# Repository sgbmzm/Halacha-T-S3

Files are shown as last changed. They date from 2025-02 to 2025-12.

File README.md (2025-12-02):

# Halacha-watch-T-DISPLAY-S3

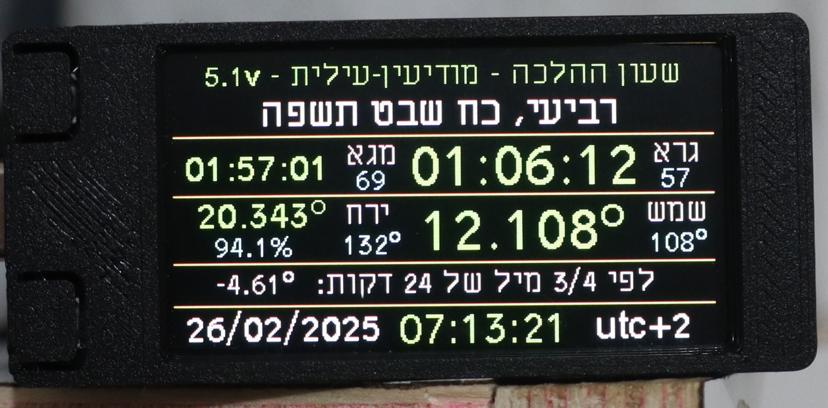
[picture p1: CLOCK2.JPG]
clock


## License  
**The file `main_shemesh_s3` is for personal use only!**  
**Modification is strictly prohibited.** You may use it as-is, but you may not edit, modify, or alter its content.  
**Commercial use is forbidden.** If you wish to use `main_shemesh_s3` for business or organizational purposes, please contact the author.  

Other files in this repository may have different licensing terms.

I would especially like to mention and thank the following important things that are freely licensed and I use them:
1. https://github.com/russhughes/s3lcd/blob/main/firmware/GENERIC_S3_OCT_16M/firmware.bin
2. https://github.com/peterhinch/micropython-samples/tree/d2929df1b4556e71fcfd7d83afd9cf3ffd98fdac/astronomy

## hardware

The hardware needed is:
This microcontroller:
https://lilygo.cc/products/t-display-s3?variant=42284559827125
solder 5 pins to it for an RTC clock called: **DS3231 MINI**
G+NC+16+21+17 (next to each other)
(DS3231 MINI can be purchased separately on AliExpress and includes a backup battery for the clock)

Attention! To prevent the DS3231 backup battery from draining quickly, it is very important to remove the 2 PULL_UP resistors located on the back of the main board and responsible for pins 16 and 17 according to the instructions here. They must be carefully removed with a soldering iron.

https://github.com/Xinyuan-LilyGO/T-Display-S3/issues/313





BATTERY:



**Please note: You need to request that the order of the wires be as shown here in the picture down**

A6b3ef4dbb0394ad195ca8c3004ead0fc0

5 pcs 3.7V 650mAh Lipo Polymer Lithium Rechargeable Battery + JST 1.25mm 2pin Plug 602248 For MP3 GPS Recorder Headset Camera

https://aliexpress.com/item/1005001397326160.html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

## INSTALL

First install (using Tony) the file:
https://github.com/sgbmzm/Halacha-T-S3/blob/main/rom/firmware_t_display_s3_s3lcd.bin
or directly from here:
https://github.com/russhughes/s3lcd/blob/main/firmware/GENERIC_S3_OCT_16M/firmware.bin

Then connect to WIFI and install the necessary files using the following code:

```
import network
import time

# פרטי הרשת שלך
SSID = "SSID_NAME" # Enter your network name (as string).
PASSWORD = "123456789" # Enter your network password (as string).

def connect_wifi():
    wlan = network.WLAN(network.STA_IF)  # מצב תחנת WiFi
    wlan.active(True)  # הפעלת WiFi
    if not wlan.isconnected():
        print("מתחבר לרשת WiFi...")
        wlan.connect(SSID, PASSWORD)  # חיבור לרשת
        while not wlan.isconnected():
            time.sleep(1)  # המתן לחיבור
    print("מחובר ל-WiFi בהצלחה!")
    print("כתובת IP:", wlan.ifconfig()[0])  # הצגת כתובת IP

# קריאה לפונקציה
connect_wifi()

import mip
mip.install("github:sgbmzm/Halacha-T-S3/package.json",target="/")
```

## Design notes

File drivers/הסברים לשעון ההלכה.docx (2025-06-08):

בס"ד

שעון ההלכה

מאת: שמחה גרשון בורר (מתכנת "כוכבים וזמנים") 052-766-1249 - sgbmzm@gmail.com

כל הזכויות שמורות

המטרה הכללית של שעון ההלכה היא: לתת את מקורות זמני ההלכה במקום את תרגומם לשעון הרגיל: 1. שעון כללי לזמני הלכה: שעות זמניות. 2. כל זמני צאת הכוכבים ועלות השחר: גובה/עומק השמש במעלות זווית תחת האופק, שזה הגורם הראשי הקובע את רמת החשיכה (ניתן להמרה ממקום למקום ומעונה לעונה).

בשעון ההלכה יש 6 שורות תצוגה:

1: כותרת, הכוללת בתוכה מיקום (עיר) ואחוזי הסוללה.

2. תאריך עברי (בשבת וחג ברקע צהוב, ובראש חודש וחול המועד ברקע טורקיז).

3. שעה זמנית לפי גר"א/מג"א וגם - מספר דקות בשעה זמנית/מספר שניות בדקה זמנית (כשבר עשרוני) - לפי השיטות הנ"ל.

4. גובה ואזימוט של השמש והירח ואחוזי הירח במסלולו החודשי ממולד למולד.

5: הסברים מתחלפים (תאריך הגרסה של שעון ההלכה מופיע מיד בתחילת ההסברים).

6: שעה בשעון רגיל, תאריך לועזי, והפרש הזמן המקומי מגריניץ (UTC).

וראו עוד הסברים להלן:

הסבר על שני הלחצנים

כששני הלחצנים בצד שמאל:

לחצן תחתון משמש להדלקה וכיבוי (לחיצה אחת קצרה).

לחצן עליון: משמש לביצוע פעולות כדלהלן

לחיצה קצרה: שינוי מיקום

לחיצה מתמשכת: הגדרת המיקום להיות מיקום ברירת מחדל כלומר שהוא המיקום שיהיה מיד כשיופעל המכשיר

הדלקה ומיד כשכתוב "מתחיל" לחיצה ארוכה על הלחצן העליון: עדכון השעון הפנימי

הדלקה בשני הלחצנים יחד: עדכון כל התוכנה

כל העדכונים דורשים שתהיה בסביבה רשת אלחוטית ללא סיסמה (כגון להפעיל נקודה חמה ללא סיסמה)

כללי

כשהשעון הפנימי מכוון: דיוק הזמנים 10 שניות, אבל: דיוק גובה הירח סוטה בכדקה

כששעון ההלכה אינו מחובר לחשמל הוא נכבה מעצמו אחרי כדקה וחצי, למעט בשבת וחג שאז נשאר דולק למשך כ- 8 שעות עד שנגמרת הבטרייה.

אחוז הסוללה (הערכה גסה בלבד) מופיע בשורת הכותרת מצד שמאל. כשמחובר לחשמל מופיע: %**

כשרואים דרך החור שיש בפנים אור אדום דולק: הסוללה נטענת. אם יש רק אור ירוק: הסוללה טעונה במלואה.

התאריך העברי מתחלף בשקיעה, ומהשקיעה ועד 23:59:59 מופיע "ליל" היום הבא.

מתחת הכיתוב גרא/מגא: דקות בשעה זמנית/שניות בדקה זמנית (כשבר עשרוני).

מתחת הכיתוב שמש/ירח: אזימוט שמש/ירח (אזימוט = מעלות זווית מהצפון, וכדלהלן: צפון=0/360, מזרח=90, דרום=180, מערב=270)

שלב הירח במסלולו החודשי - ממולד אמיתי למולד אמיתי – באחוזים - מתחת לגובה הירח: מולד אמיתי=0/100, ניגוד=50, רבָעִים=25/75

רשימת זמני היום בשעות זמניות

זריחה ושקיעה במישור: 00:00

סוף שמע ביום/רבע הלילה: 03:00

סוף תפילה ביום/שליש הלילה//סוף אכילת חמץ: 04:00

סוף שריפת חמץ: 05:00

חצות יום ולילה: 06:00

מנחה גדולה: 06:30 (ויש סוברים 30 דקות אחרי חצות)

להימנע מסעודה בערב שבת: 09:00

מנחה קטנה: 09:30

פלג המנחה: 10:45

הערה חשובה: שעה זמנית מג"א מחושב לפי 72 דקות בתקופת ניסן (בבוקר ובערב כדי שחצות יהיה בראש כל אדם) ומתורגם למעלות לפי שמש בגובה 16°- בבוקר ובערב. (שימו לב שברוב הלוחות נותנים זמן מג"א לפי 90 דקות שזה במעלות °19.75- אך דבר זה קשה להתאימו עם המציאות של הארת הרקיע בבוקר ובערב ולכן לא הבאתיו).

זמנים במעלות כשהשמש תחת האופק

זריחת ושקיעת מרכז השמש ללא התחשבות ברפרקציה (גאומטרי): 0.0°

זריחה ושקיעה נראים במישור וכשאין הסתרות: 0.833°-

זמני צאת הכוכבים 3/4 מיל מתורגמים למעלות

לפי מיל של 18 דקות: -3.65°

לפי מיל של 22.5 דקות: -4.2°

לפי מיל של 24 דקות: -4.61°

צאת כוכבים קטנים רצופים (בחגורת הצייד לפי תצפיות שלי): -6.3° (בין 6 ל 6.5 מעלות)

זמני עלות השחר/צאת כוכבים דר"ת מתורגמים למעלות

לפי 4 מיל של 18 דקות: -16.02°

לפי 4 מיל של 22.5 דקות: -19.75°

לפי 5 מיל של 24 דקות: -25.8°

משיכיר/תחילת ציצית ותפילין (משוער לפי תצפיות): -10.5°

להלן תנאי מינימום (בערך) הדרושים לראיית ירח ראשונה בחודש

שלב חודשי: 3%; וגם הפרש גובה שמש-ירח של 8°

פתרון תקלות:

בכל תקלה יש לנסות ללחוץ על לחצן האיפוס בחור שנמצא בחלק העליון.

בבליטה שמאחורי המכסה יש שעון פנימי שאמור לשמור על התאריך והשעה גם כשנגמרת הבטרייה, אך לפעמים הוא עושה בעיות. ניתן לנסות לכוון אותו באמצעות רשת אלחוטית ללא סיסמה וכדלעיל, ואם לא מועיל - אפשר להחליף אותו אצלי תמורת 5 ₪.

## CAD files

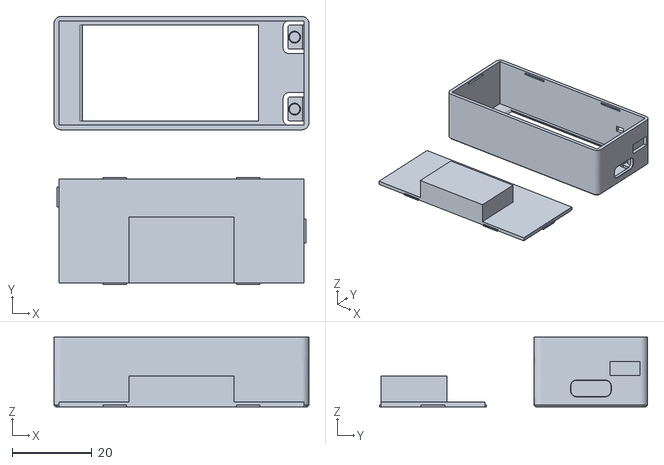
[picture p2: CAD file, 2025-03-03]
S3_SHELL_AND_COVER.stl
63.8 x 67.1 x 17.4

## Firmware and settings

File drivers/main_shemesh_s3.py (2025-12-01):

# ========================================================
# License: Personal Use Only  
# This file (`main_shemesh_s3.py`) is licensed for **personal use only**.  
# You may **not** modify, edit, or alter this file in any way.  
# Commercial use is strictly prohibited.  
# If you wish to use this file for business or organizational purposes,  
# please contact the author.  
# ========================================================

# משתנה גלובלי שמציין את גרסת התוכנה למעקב אחרי עדכונים
VERSION = "1/12/2025"

######################################################################################################################

# סיכום קצר על התוצאות המעשיות של הכפתורים בקוד הזה
# לחיצה על שתי הכפתורים בו זמנית כאשר מדליקים את המכשיר: עדכון תוכנת המכשיר
# אם כפתור המיקומים לחוץ בשעת הכניסה לתוכנה: עדכון השעון מהרשת 

# הבסיס של החישובים הגיע מכאן
# https://github.com/peterhinch/micropython-samples/tree/d2929df1b4556e71fcfd7d83afd9cf3ffd98fdac/astronomy
# לגבי בעיות עם המסך שבס"ד נפתרו ראו כאן
# https://github.com/Xinyuan-LilyGO/T-Display-S3/issues/300

import time, math, machine, utime, esp32, network, ntptime, os, ujson
from math import sin, cos, tan, radians, degrees
from machine import I2C, SoftI2C, Pin, ADC, PWM, RTC
import gc # חשוב נורא לניקוי הזיכרון
from halacha_clock.sun_moon_sgb import RiSet  # ספריית חישובי שמש
from halacha_clock.moonphase_sgb import MoonPhase  # ספריית חישובי שלב הירח
from halacha_clock.ds3231 import DS3231 # שעון חיצוני
from halacha_clock import mpy_heb_date # לחישוב תאריך עברי מתאריך לועזי. ספרייה שלי


# פונטים
import halacha_clock.miriam20 as FontHeb20
import halacha_clock.miriam25 as FontHeb25
import halacha_clock.miriam30 as FontHeb30
import halacha_clock.miriam40 as FontHeb40

# למסך
import halacha_clock.tft_config as tft_config
import s3lcd

# הגדרת המסך
tft = tft_config.config(rotation=3) # כיוון סיבוב התצוגה שאני רוצה בגלל הבליטה של השעון החיצוני
tft.init() # כך חייבים לעשות

####################################################################3


# הגדרת הכפתורים הפיזיים במכשיר
boot_button = Pin(0, Pin.IN, Pin.PULL_UP) # משמש בקוד לשינוי המיקומים ולקביעת מיקום ברירת מחדל
button_14 = Pin(14, Pin.IN, Pin.PULL_UP) # משמש בקוד להכנסת המכשיר למצב שינה ולהתעוררות ולשליטה על הכוח

    
# משתנה למעקב אחר מצב הכוח כלומר האם המכשיר כבוי או פועל
# המשמעות של זה מגיעה לידי ביטוי בפונקצייה הראשית: main
# זה משתנה חשוב נורא
power_state = True

# משתנה מאוד חשוב שמגדיר האם המכשיר ייכנס למצב שינה אוטומטי לאחר מספר דקות של פעילות
# המשתנה הזה מוגדר בתוך פונקציית main_halach_clock לפי אם שבת או יום חול
automatic_deepsleep = False

##########################################################################################################
# הגדרת ADC על GPIO4 לצורך קריאת כמה מתח המכשיר מקבל
adc = ADC(Pin(4))  
adc.atten(ADC.ATTN_11DB)  # קביעת טווח מתח עד כ-3.6V
adc.width(ADC.WIDTH_12BIT)  # רזולוציה של 12 ביט (ערכים בין 0 ל-4095)

# משתנה חשוב שמגדיר מה המתח המירבי שיכול להיות לסוללה הפנימית ומעל זה קובעים שסימן שמחובר לחשמל או למקור מתח חיצוני
max_battery_v = 4.55

# משתנה מאוד חשוב ששומר את המתח בשנייה הקודמת כדי להשוות אליו ולבדוק האם חובר חשמל או נותק
# זה מתעדכן כל שנייה מחדש בפונקציית מיין-מיין
last_voltage = None # שומר את המתח האחרון שנמדד
last_battery_percentage = None # שומר את אחוזי הסוללה האחרונים שנמדדו
last_is_charging = None # שולט על כל הדברים שדורשים לדעת האם כעת המכשיר מחובר לחשמל

# פונקציה למדידת מתח סוללה מתוך ממוצע של 10 קריאות מתח
# מספר הקריאות משפיע על מהירות פעילות התוכנה. כמה שיותר קריאות התוכנה מתעכבת יותר !!!!!!!!!!!!!
def read_battery_voltage(samples=8):
    total = 0
    for _ in range(samples):
        total += adc.read()
        time.sleep(0.005)  # חצי מילישנייה בין קריאות
    avg = total / samples
    voltage = (avg / 4095) * 3.6 * 2  # המרה למתח אמיתי
    return voltage

# כדי לדעת אם מחובר כעת לחשמל, כדאי לבדוק מספר קריאות רצופות
# מספר הקריאות משפיע על מהירות פעילות התוכנה. כמה שיותר קריאות התוכנה מתעכבת יותר !!!!!!!!!!!!!!
def is_charging_function(voltage, threshold=max_battery_v, stable_reads=1):
    count = 0
    for _ in range(stable_reads):
        if read_battery_voltage() > threshold:
            count += 1
        time.sleep(0.005)
    return count >= stable_reads

def get_battery_percentage(voltage, min_voltage=3.6, max_voltage=4.4):
    """ מחשב אחוז סוללה על פי המתח הנמדד ומונע ערכים מחוץ לטווח 0%-100% """
    percentage = ((voltage - min_voltage) / (max_voltage - min_voltage)) * 100
    return round(max(0, min(100, percentage)))


##############################################3

# לאחר מכן להפעיל PWM כדי לשלוט במידת התאורה האחורית של המסך
BACKLIGHT = PWM(Pin(38, Pin.OUT), freq=2000) # ה: פרק, חשוב מאוד לגבי התדר וקובע גם את סוג הצפצופים שנשמעים בעיקר כשמחובר לחשמל
PWM_MAX = 1023 # תאורה הכי גבוהה
PWM_MIN = 0 # התאורה כבוייה

#############################################

# משתנה גלובלי שמפנה לשעון הפנימי של המכשיר
rtc_system = machine.RTC()

###########################################################################################################

#הגדרת ערוצי I2C הגדרת האם ולאיפה מחוברים DS3231 שזה שעון חיצוני וגם BME280 שזה חיישן טמפרטורה

# יצירת אובייקט I2C עם נגדי pull-up פנימיים עבור הפינים שהלחמתי במכשיר
# אם מגדירים את הפינים ישירות בלי נגדים פנימיים זה עושה כאילו יש הרבה התקני I2C מחוברים למרות שבאמת אין
solder_pin_plus = Pin(17, Pin.OUT, value=1) # חייבים קודם להפעיל כך את הפין החיובי המולחם אחרת החיישן שמחובר ל I2C המולחם לא יעבוד
solder_pin_scl = Pin(16, Pin.OPEN_DRAIN, pull=Pin.PULL_UP)
solder_pin_sda = Pin(21, Pin.OPEN_DRAIN, pull=Pin.PULL_UP)
solder_pins_i2c = SoftI2C(scl=solder_pin_scl, sda=solder_pin_sda)

# זה I2C הרגיל המובנה במכשיר והוא כבר יש לו נגדים מובנים
original_i2c = I2C(scl=Pin(44), sda=Pin(43), freq=20000) # חייבים כזה freq בגלל שלפעמים הכבל של החיישן ארוך מטר

######################################################################################################

# משתנים גלובליים של שמות ההתקנים שיכולים להיות מחוברים ליציאת I2C עבור תוכנה זו
ds3231_bitname = 0x68 

# פונקצייה מאוד חשובה שבודקת האם ולאיפה מחוברים DS3231 או BME280 מתוך יציאות I2C שהוגדרו לעיל
def check_i2c_device(device_bitname):
    
    # סריקת כל אחד מ I2C כדי לדעת אילו התקנים מחובר לכל אחד
    original_i2c_devices = original_i2c.scan()
    solder_pins_i2c_devices = solder_pins_i2c.scan()
  
    # משתנים ששומרים תשובה בנכון או לא נכון לשאלה האם DS3231 ו/או BME280 מחוברים או לא מחוברים
    is_device_connected = device_bitname in original_i2c_devices or device_bitname in solder_pins_i2c_devices
    
    # אם מחובר DS3231, צריך לבדוק לאיפה
    if is_device_connected:
        # הגדרת כתובת I2C נכונה עבור SD3231 ושם היציאה שאליה מחובר
        device_exit, device_exit_name = (original_i2c, "יציאה חיצונית") if device_bitname in original_i2c_devices else (solder_pins_i2c, "פינים מולחמים")
        
    else:
        device_exit, device_exit_name = None, None
      
  
    return is_device_connected, device_exit, device_exit_name


############################################################################################

# במיקרופייתון אין פונקציית time.strftime ולכן מחליף כך
def format_time(time_tuple, with_seconds = True, with_date=False):
    """המרת tuple של זמן למחרוזת בסגנון HH:MM:SS,  או '%H:%M:%S %d/%m/%Y'"""
    t = time_tuple
    return f"{t[3]:02d}:{t[4]:02d}:{t[5]:02d} {t[2]:02d}/{t[1]:02d}/{t[0]}" if with_date else f"{t[3]:02d}:{t[4]:02d}:{t[5]:02d}" if with_seconds else f"{t[3]:02d}:{t[4]:02d}"

# פונקצייה להמרת זמן מ-שניות ל- סטרינג שעות דקות ושניות, או רק ל- סטרינג דקות ושניות שבניתי בסיוע רובי הבוט
def convert_seconds(seconds, to_hours=False):
    # המרה לערך מוחלט כדי לא להחזיר סימן מינוס
    seconds = abs(seconds)
    # חישוב מספר הדקות והשניות שיש בשעה אחת, והדפסתם בפורמט של דקות ושניות
    if to_hours:
        return f'{seconds // 3600 :02.0f}:{(seconds % 3600) // 60 :02.0f}:{seconds % 60 :02.0f}'
    else:
        return f'{seconds // 60 :02.0f}:{seconds % 60 :02.0f}'


def calculate_delta_t(year):
    """
    Calculate ΔT (seconds) for years 2000-2500 using the polynomial expressions.
    https://eclipse.gsfc.nasa.gov/SEhelp/deltatpoly2004.html
    """
    y = float(year)
    
    if 2000 <= y < 2005:
        t = y - 2000
        dt = 63.86 + 0.3345*t - 0.060374*t**2 + 0.0017275*t**3 + 0.000651814*t**4 + 0.00002373599*t**5
    elif 2005 <= y < 2050:
        t = y - 2000
        dt = 62.92 + 0.32217*t + 0.005589*t**2
    elif 2050 <= y < 2150:
        u = (y - 1820)/100
        dt = -20 + 32*u**2 - 0.5628*(2150 - y)
    else:  # y >= 2150
        u = (y - 1820)/100
        dt = -20 + 32*u**2

    # Small lunar correction (not needed for 1955-2005, but outside this range we apply)
    if y < 1955 or y > 2005:
        dt += -0.000012932 * (y - 1955)**2

    return dt


# פונקצייה שמקבלת זמן כחותמן זמן ומחזירה את משוואת הזמן בדקות ליום זה
# לפי Meeus, בקירוב מצוין לשנים 2000–2100
# נבנתה על ידי צאט גיפיטי
def get_equation_of_time_from_timestamp(timestamp_input):
    
    # פונקצייה לקבלת זמן באלפי שנים מאז J2000.0 וגם יום יוליאני לצורך חישובים אסטרונומיים
    def get_julian_centuries_since_J2000_and_jd(timestamp):
        JD = timestamp / 86400.0 + 2440587.5
        JC = (JD - 2451545.0) / 36525.0
        return JC, JD
    
    # קבלת זמן באלפי שנים מאז J2000.0 לצורך החישובים, באמצעות הפונקצייה הנל
    T, JD = get_julian_centuries_since_J2000_and_jd(timestamp_input)

    # ואז ממשיכים כמו קודם:
    L0 = radians((280.46646 + 36000.76983 * T) % 360)
    e = 0.016708634 - 0.000042037 * T
    M = radians((357.52911 + 35999.05029 * T) % 360)
    y = tan(radians(23.439291 - 0.0130042 * T) / 2)
    y *= y
    equation_of_time_minutes = 4 * degrees(
        y * sin(2 * L0)
        - 2 * e * sin(M)
        + 4 * e * y * sin(M) * cos(2 * L0)
        - 0.5 * y * y * sin(4 * L0)
        - 1.25 * e * e * sin(2 * M)
    )
    
    equation_of_time_seconds = equation_of_time_minutes * 60
    
    return equation_of_time_seconds


# פונקצייה לחישוב זמן מקומי (לפי חצות שנתי ממוצע שהוא בשעה 12), לפי קו האורך הגיאוגרפי האמיתי 
def LMT_LST_EOT(utc_timestamp, longitude_degrees, LST_EOT = True):
    offset_seconds = int(240 * longitude_degrees)  # 4 דקות לכל מעלה
    lmt_seconds = int(utc_timestamp) + offset_seconds # חייבים לעשות אינט למנוע שגיאות במיקרופייתון
    lmt_tuple = time.gmtime(int(lmt_seconds))   # לא מוסיף הטיה מקומית
    local_mean_time_string = format_time(lmt_tuple)
    ####################################################################
    if LST_EOT:
        equation_of_time_seconds = get_equation_of_time_from_timestamp(utc_timestamp)
        lst_seconds = lmt_seconds + int(equation_of_time_seconds) # חייבים לעשות אינט למנוע שגיאות במיקרופייתון
        lst_tuple = time.gmtime(int(lst_seconds))
        local_solar_time_string = format_time(lst_tuple)
        equation_of_time_string = f"{'+' if equation_of_time_seconds >0 else '-'}{convert_seconds(equation_of_time_seconds)}"
    else:
        local_solar_time_string, equation_of_time_string = "None","None"
    return local_mean_time_string, local_solar_time_string, equation_of_time_string

# פונקצייה לקבלת הפרש השעות המקומי מגריניץ בלי התחשבות בשעון קיץ
# יש אפשרות להגדיר טרו או פאלס האם זה שעון קיץ או לא. כברירת מחדל זה לא
# אפשר להגדיר האם רוצים את ההפרש בשעות או בשניות וברירת המחדל היא בשעות
def get_generic_utc_offset(longitude_degrees, dst=False, in_seconds = False):
    offset = abs(round(longitude_degrees/15)) % 24
    offset = -offset if longitude_degrees < 0 else offset
    offset = offset + 1 if dst else offset
    return offset * 3600 if in_seconds else offset
    
# פונקצייה להפיכת טקסט כדי שעברית תהיה משמאל לימין
def reverse(string):
    return "".join(reversed(string))

# מקבל מספר יום בשבוע לפי הנורמלי ומחזיר את מספר היום בשבוע לפי ההגדרות ב RTC
def get_rtc_weekday(weekday):
    rtc_weekday_dict = {1:6,2:0,3:1,4:2,5:3,6:4,7:5}
    return rtc_weekday_dict.get(weekday)

# מוציא את מספר היום בשבוע הנורמלי לפי סדר מתוך שעון המכשיר שמוגדר RTC
def get_normal_weekday(rtc_weekday):
    weekday_dict = {6:1,0:2,1:3,2:4,3:5,4:6,5:7}
    return weekday_dict.get(rtc_weekday)

# פונקצייה שמחזירה נכון או לא נכון האם נוהג שעון קיץ בישראל לזמן המבוקש
# היא מתבססת על מה השעה והתאריך ברגע זה בשעון הפנימי של המיקרו בקר ולכן חייבים להגדיר אותו לפני שקוראים לפונקצייה זו
# שעון הקיץ מופעל בישראל בין יום שישי שלפני יום ראשון האחרון של חודש מרץ בשעה 02:00, לבין יום ראשון האחרון של חודש אוקטובר בשעה 02:00.
# השעה 2 בלילה של שינוי השעון הם בשעון ישראל ואילו שעון הבקר מוגדר לאיזור זמן גריניץ לכן הקדמתי בשעתיים לשעה 0 שעון גריניץ
def is_israel_DST(timestamp):
    """
    timestamp: מספר שניות מאז Epoch (1970-01-01 00:00:00 UTC)
    מחזיר True אם הזמן הוא בשעון קיץ בישראל, אחרת False
    """
    # המרת timestamp ל-localtime כדי לדעת את השנה
    t = utime.localtime(timestamp)
    year = t[0]

    # --- חישוב יום ראשון האחרון של מרץ ---
    march_last_sunday = utime.mktime((year, 3, 31, 0, 0, 0, 0, 0, 0))
    while utime.localtime(march_last_sunday)[6] != get_rtc_weekday(1):
        march_last_sunday -= 86400  # יום אחורה
    
    # יום שישי שלפני יום ראשון האחרון של מרץ
    last_friday_march = march_last_sunday - 2 * 86400

    # --- חישוב יום ראשון האחרון של אוקטובר ---
    october_last_sunday = utime.mktime((year, 10, 31, 0, 0, 0, 0, 0, 0))
    while utime.localtime(october_last_sunday)[6] != get_rtc_weekday(1):
        october_last_sunday -= 86400

    # --- בדיקה אם בתוך תקופת שעון קיץ ---
    return last_friday_march <= timestamp < october_last_sunday



# פונקצייה לפריטת שעה בשבר עשרוני לשניות
# אחר כך אפשר להשתמש בפונקצייה הקודמת להמרת של השניות לשעות דקות ושניות בפורמט שעון
# פונקצייה זו יכולה להיות שימושים לצורך נתינת עלייה ישרה בפורמט של שעות דקות ושניות אך כרגע אין לה שימוש בקוד זה
def decimal_hours_to_seconds(decimal_hours):
    hours = int(decimal_hours)  # קבלת השעות השלמות
    minutes_decimal = (decimal_hours - hours) * 60  # המרת החלק השברי לדקות
    minutes = int(minutes_decimal)  # קבלת הדקות השלמות
    seconds = (minutes_decimal - minutes) * 60  # המרת החלק השברי של הדקות לשניות
    total_seconds = hours * 3600 + minutes * 60 + seconds
    return total_seconds

#################################################################################################

# חישוב מה מרכז המסך כדי למרכז את הטקסט במרכז המסך
# עדיין יש בעיות קטנות שאולי נגרמות מכך שיש אותיות צרות יותר מ MAX_WIDTH אבל אין מה לעשות כרגע
# בינתיים זה הכי טוב שהגעתי אליו
def center(text, font):
    # הגדרת הפיקסל שבמרכז המסך
    tft_pixel_center = 160 # tft.width() // 2
    # הגדרת הפיקסל שבמרכז הטקסט
    text_pixel_center = tft.write_len(font, text) // 2 # write_len מחזיר את רוחב השורה בפיקסלים. וחצי מזה זה הפיקסל שבאמצע הטקסט
    # פעם השתמשתי הרבה פחות מוייק ב text_pixel_center = len(text) // 2 * font.MAX_WIDTH // 2 # כלומר הרוחב בפיקסלים של חצי מהטקסט
    return tft_pixel_center - text_pixel_center # זה אומר כמה ימינה ממרכז המסך צריך להתחיל את ההדפסה כדי שמרכז ההדפסה יהיה במרכז המסך


######################################################################################################3

# פונקצייה מאוד חשובה לקביעה כמה זמן לחצו על כפתור האם לחיצה ארוכה או קצרה
def handle_button_press(specific_button):
    start_time = time.ticks_ms()
    # הלולאה הזו מתבצעת אם לוחים ברציפות בלי לעזוב
    while specific_button.value() == 0:  # כל עוד הכפתור לחוץ
        if time.ticks_diff(time.ticks_ms(), start_time) > 2000:  # לחיצה ארוכה מעל 2 שניות
            return "long"
    # מכאן והלאה מתבצע רק אחרי שעוזבים את הכפתור ואז מודדים כמה זמן היה לחוץ
    if 100 < time.ticks_diff(time.ticks_ms(), start_time) < 1000: # לחיצה קצרה מתחת לשנייה אחת אבל מעל 100 מיקרו שניות כדי למנוע לחיצה כפולה
        return "short"
    return None  # במידה ולא זוהתה לחיצה


# פונקצייה נורא חשובה שעושה כמה פעולות קריטיות בלחיצה על כפתור ההפעלה/כיבוי
# 1: מפעילה או מכבה 2: מחזירה למיקום ברירת מחדל. 3: מאפסת את המשתנה של הזמן שלפיו נקבע מתי יכבה המסך מעצמו
def toggle_power(pin):
    
    button_14.irq(handler=None)  # השבתת ה-IRQ כדי למנוע הפעלה כפולה של פונקצייה זו
    
    # המשתנה הגלובלי ששולט על האם לכבות או להדליק
    global power_state
    
    # הפיכת המצב גורמת להדלקה או כיבוי שמתבצעת בפועל בפונקצייה הראשית מיין-מיין
    power_state = not power_state 
    #  תזכורת שפעם שלא הלכנו לשינה עמוקה עשיתי כאן import main וזה התחיל הכל מהתחלה

    # המתנה כדי למנוע לחיצה כפולה
    while button_14.value() == 0:  # ממתין שהכפתור ישתחרר
        time.sleep_ms(50)
    
    button_14.irq(trigger=Pin.IRQ_FALLING, handler=toggle_power)  # הפעלת ה-IRQ מחדש לאחר שסיימנו את הפעולה של הפונקצייה
            

# חיבור הכפתור לפונקציה הנל. לחיצה על הכפתור קוראת לפונקצייה שמעדכנת את משתנה הכוח
# כרגע מתבצע באמצעות כפתור בוט אבל אפשר גם באמצעות הכפתור השני
button_14.irq(trigger=Pin.IRQ_FALLING, handler=toggle_power)

######################################################################################################
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

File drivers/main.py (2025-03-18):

from machine import Pin

# למסך
import halacha_clock.tft_config as tft_config
import s3lcd
import halacha_clock.miriam25 as FontHeb25

# פונקצייה להפיכת טקסט כדי שעברית תהיה משמאל לימין
def reverse(string):
    return "".join(reversed(string))

# הצגת הודעה על המסך כמה שיותר מהר כדי שיראו שהכל בסדר
# אסור להגדיר כאן את בהירות המסך כי זה גרם לכך שכשמחובר לחשמל המסך לא נכבה בלחיצה על כיבוי כשלא היה מצב שינה עמוקה
try:
    tft = tft_config.config(rotation=3) # כיוון סיבוב התצוגה שאני רוצה
    tft.init() # כך חייבים לעשות
    tft.fill(0) # מחיקת המסך
    tft.write(FontHeb25,f'{reverse("מתחיל...")}',200,20)
    #tft.line(0, 45, 320, 45, s3lcd.YELLOW)
    tft.show()
finally:
    tft_config.deinit(tft)

# הגדרת הכפתורים הפיזיים במכשיר
boot_button = Pin(0, Pin.IN, Pin.PULL_UP) # משמש בקוד לשינוי המיקומים ולקביעת מיקום ברירת מחדל
button_14 = Pin(14, Pin.IN, Pin.PULL_UP) # משמש בקוד להכנסת המכשיר למצב שינה ולהתעוררות ולשליטה על הכוח

# אם שני הכפתורים לחוצים בעשה שהמכשיר מאותחל אז קוראים לפוקציית עדכון שעון ההלכה
if boot_button.value() == 0 and button_14.value() == 0:
    from halacha_clock import update_halacha_clock

# בכל מקרה אחר מפעילים את שעון ההלכה
else:
    from halacha_clock import main_shemesh_s3

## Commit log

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2025-02-17 Update main_shemesh_s3.py
    זיהוי מתח חיבור לחשמל 4.6 במקום 5 כדי למנוע קפיצות של רמת התאורה סביב 5 וולט. כי זיהוי הוולט אינו מדוייק לחלוטין ויש בו קפיצות. הכי טוב היה לעשות ממוצע אבל אולי בעתיד
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2025-02-23 Update main.py
    אם מחובר חיישן bme280 מפעילים את התוכנה שלו ואם לא מחובר אז מפעילים את שעון ההלכה
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2025-02-24 Update and rename sun_moon.py to sun_moon_sgb.py
    הוספת פונקצייה חשובה מאוד alt_az_ra_dec
    ושינוי שם הספרייה ל sun_moon_sgb
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2025-02-26 Update main_shemesh_s3.py
    ביטול הדפסות והשהיה בכניסה למצב שינה. מצב שינה מתבצע מיד בלחיצה על הכפתור
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2025-02-28 Update main_shemesh_s3.py
    הגדרת המסך בכניסה למצב שינה כדי לנסות לפתור מריחת מסך כשהמכשיר בכיס
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2025-03-03 Update main_shemesh_s3.py
    שינוי טקסט בכיבוי ושינוי מוצאי רק משהשמש בגובה יותר נמוך ממינוס 4 מעלות אחרי השקיעה
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2025-03-05 Update main_shemesh_s3.py
    1. ביטול נסיונות עדכון חוזרים של השעון החיצוני כשלא עודכן מעולם
    2. הגדרה שאם המתח החשמלי נמוך מ 3.8 וולט המכשיר ייכבה
2025-03-06 Update main_shemesh_s3.py
    הגדרות I2C בשתי אופציות ובדיקות האם DS3231 ו/או BME280 מחוברים ואם כן אז לאיפה מחוברים
2025-03-08 Update main_shemesh_s3.py
    עדכון מאוד גדול שבעיקר משנה את כל הטיפול בעדכון הזמן מפונקציית
    sync_rtc_with_ds3231()
    לפונקציית
    check_and_set_time()
    כולל כל השינויים היוצאים מכך
2025-03-09 Update main_shemesh_s3.py
    עדכון משמעותי שני להיות!
    מכניס את מד טמפרטורה לחות ולחץ BME280 לתוך הקוד הראשי הזה
    הרבה דברים השתנו בעקבות כך
    כמו כן אין כבר צורך בקובץ main_bme280.py וצריך למחוק אותו
2025-03-09 Update main.py
    הפסקת טיפול ב BME280 כאן, כי מטופל בקוד הראשי של main_shemesh_s3
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2025-03-09 Update main_shemesh_s3.py
    נוסף קוד זמני למחיקת הקובץ המיותר main_bme280.py
    כמו כן הקובץ ששומר מיקום ברירת מחדל הועבר לתוך תיקיית התוכנה
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2025-03-09 Update main_shemesh_s3.py
    הוספת מחיקה לקובץ default_location.txt ממיקומו הישן כי הוא עבר לתיקייה הראשית
2025-03-09 Update main_shemesh_s3.py
    עדכון חשוב של פונקציית check_and_set_time לטיפול בבאג חמור שלא נתן לעדכן מהרשת כאשר DS3231 מחובר
2025-03-12 Update main_shemesh_s3.py
    המון שינויים חשובים ועיקרם שהמכשיר/המסך נכבה אוטומטית אחרי כמה שניות של פעילות כאשר הוא מחובר רק לסוללה הפנימית ולא לחשמל. ובשבת הוא לא נכבה גם כשמחובר רק לסוללה.
    תוך כדי זה ביטלתי כרגע את שינה עמוקה והוחלף בכיבוי מסך כי זה עוזר להמון דברים ובהם שלא יהיו מריחות על המסך לאחר התעוררות משינה עמוקה
2025-03-12 Update main_shemesh_s3.py
    בהמשך לעדכון הגדול היום, תיקון שגיאה בחישוב חצי שעה לפני השקיעה במקום שאין שקיעה
2025-03-12 Update main_shemesh_s3.py
    עוד תיקונים חשובים בהמשך לעדכון הגדול שנעשה היום
    1. שיפור קריטי בפונקצייה ששולטת בפעילות כפתור הכיבוי והדלקה
    2. העברת מיקומים בחול לסוף רשימת המיקומים כי יש מהם שגורמים לשגיאות ואז כל מה שאחר כך נתקע ואי אפשר להגיע אליו.
    דוגמא לשגיאה כרגע בוילנא כשיש שקיעה אבל אין רבינו תם
2025-03-12 Update main_shemesh_s3.py
    עוד תיקון כדי שהמכשיר לא ייכבה באמצע דפדוף ברשימת המיקומים לכן לחיצה על כפתור המיקומים מאריכה זמן עד לכיבוי אוטומטי
2025-03-12 Update main_shemesh_s3.py
    העדכון הקודם נכשל באמצע ולכן אני מעדכן שוב.
    העדכון כולל טיפול בכפתור דפדוף המיקומים שדפדוף יגרום לדחיית כיבוי אוטומטי
2025-03-12 Update main_shemesh_s3.py
    תיקונים קטנים נוספים
    העברת פונקציית כפתור ההדלקה להיות לאחר פונקציית כפתור המיקומים כדי לא לגרום לבאג. כי פונקציית המיקומים מגדירה מיקום קבוע.
2025-03-12 Update main_shemesh_s3.py
    תיקונים שלחיצה על כפתור האיפוס מאפסת גם את המיקום האינדקסי הנגלל של רשימת המיקומים
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2025-03-15 Update main_shemesh_s3.py
    טיפול בשגיאה במקום שהשמש לא מגיעה לגובה הדרוש עבור מגן אברהם בתוך פונקציית מיין
2025-03-15 Update main_shemesh_s3.py
    הוספת משתנה DEEPSLEEP ששולט בכל התוכנה האם הולכים למצב שינה עמוקה או לכיבוי מסך בלבד. לידו הוספתי הסברים
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2025-03-16 Update main_shemesh_s3.py
    עדכון גדול לגבי תאריך עברי: כל חישובו עבר לספרייה נפרדת שיצרתי בשם mpy_heb_date
    בנוסף עדכונים לגבי זמן הפעולה עד לכיבוי אוטומטי ומהירות התחלפות ההסבר בשורת ההסברים
    כמו כן שיפור בקוד הכיבוי בסוף תוך הפרדה ברורה בין שינה עמוכה לבין כיבוי מסך בלבד, ושימוש ב tft_config.deinit(tft, display_off=True) לניתוק המסך במצב שינה עמוקה
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2025-03-17 Update main_shemesh_s3.py
    מניעת כיבוי אוטומטי בחגים תאריך עברי מתאים שמשתנה לאחר השקיעה ורקע מתאים לתאריך העברי
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2025-03-17 Update main.py
    הוספת הודעה "מתחיל" לפני תחילת הקוד כי לוקח לקוד זמן להיטען ובינתיים לא כדאי שהמסך יהיה ריק ויחשבו שיש בעיה
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2025-03-18 Update main.py
    # בינתיים בוטל כל החלק של מסך מתחיל... בגלל שגורם משום מה למסך לא להיכבות בזמן שמחובר לחשמל ולא מוגדר מצב שינה עמוקה
2025-03-18 Update main.py
    הוחזר בחזרה מסך ההתחלה אך בוטלה הגדרת בהירות המסך
    # אסור להגדיר כאן את בהירות המסך כי זה גרם לכך שכשמחובר לחשמל המסך לא נכבה בלחיצה על כיבוי כשלא היה מצב שינה עמוקה
2025-03-18 Update main_shemesh_s3.py
    עדכון גדול: העברת התוכנה לפעול דרך main_main ואז וייל טרו שמפעיל את main_main במקום מה שהיה עד עכשיו שכל main_main לא היה פונקצייה אלא כולו רץ ישר ב וייל טרו
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2025-10-30 Fix formatting for Hebrew strings in main_shemesh_s3.py
    [main_shemesh_s3.py]
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2025-11-02 Reset times for sunrises and sunsets on day update
    Clear previous sunrise and sunset times for the current day.
    [sun_moon_sgb.py]
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
